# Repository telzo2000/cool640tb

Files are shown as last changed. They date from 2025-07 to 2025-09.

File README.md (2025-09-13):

# cool640tb

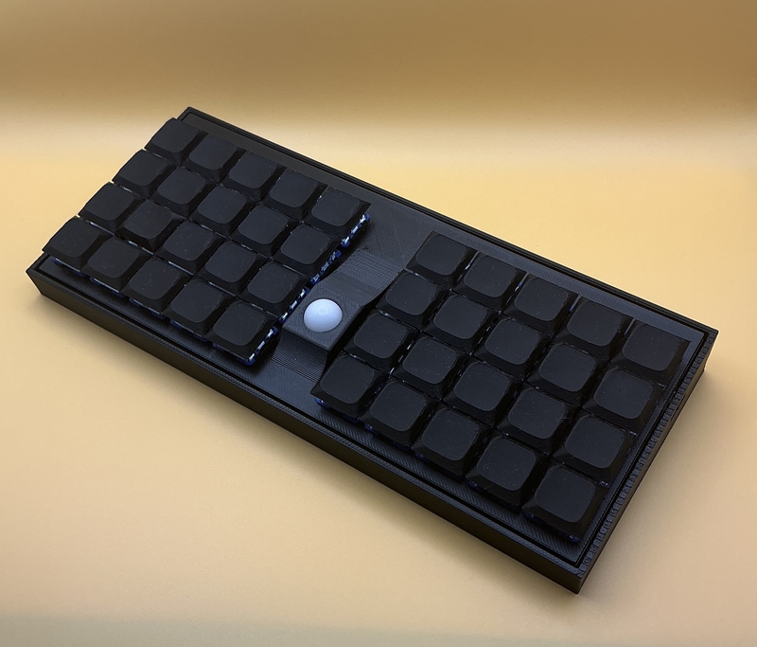
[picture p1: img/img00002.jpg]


## What is cool640tb?

cool640tb is ortholiner keyboard with trackball.

<br>
cool640tb use seeed xiao ble,run zmk_firmware.
<br>
<br>

作った理由
<br>
https://sizu.me/m_ki/posts/i3df5xan90us
<br>

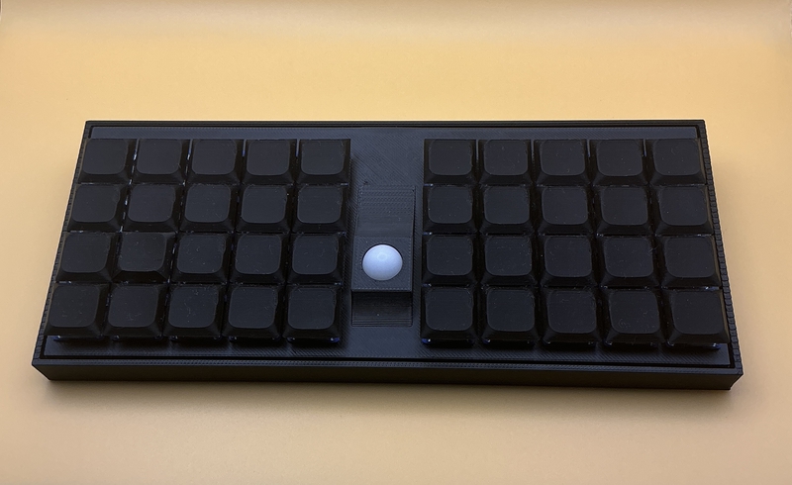
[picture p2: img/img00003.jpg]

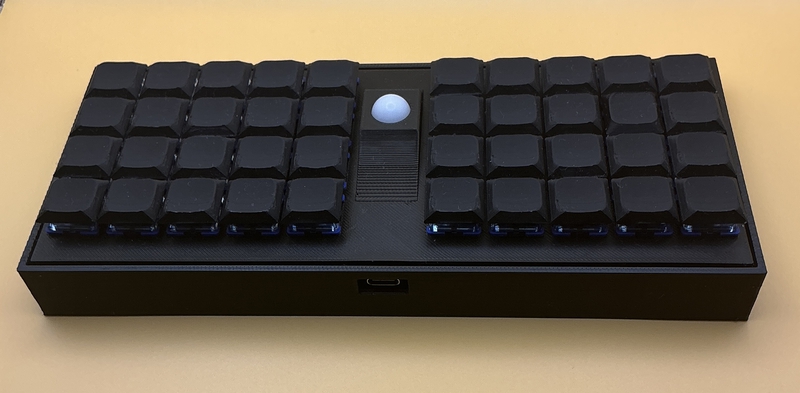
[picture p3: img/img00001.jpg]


## firmware

[zmk-config](https://github.com/telzo2000/zmk-config-cool640tb)

<br>
keymap editor

https://nickcoutsos.github.io/keymap-editor/

<br>
zmk studio

https://zmk.studio/

<br>

自作キーボードへのzmk_firmwareのインストールについて

https://sizu.me/m_ki/posts/kvixkn2mec6a

<br>
zmk_firmwareでのキーマップ編集について

https://sizu.me/m_ki/posts/m3devs7be5km

<br>

## buildguide

https://github.com/telzo2000/cool640tb/blob/main/buildguide_for_cool640tb.md

<br>
組み立てたけど、キーが反応しない時は
<br>
https://sizu.me/m_ki/posts/3vcc3izdt1w4
<br>

<br>

## BOM
<b>common parts</b>
| No. | Patrs | Quantity | remarks | Suppliers | Cost |
|--|--|--|--|--|--|
|番号|名前|数|備考|調達先|参考価格（送料込）|<br>
|1|PCB|1||[elecrow](https://www.elecrow.com)<br>[JLCPCB](https://jlcpcb.com)<br>[ALLPCB](https://www.allpcb.com)||<br>
|2|Top case|1|3D Print|||
|3|Bottom case|1|3D Print|||
|4|Switch knob|1|3D Print|||
|5|Slide switch<br>スライドスイッチ|1||[秋月電子](https://akizukidenshi.com/catalog/g/g115370/)|１個30円|
|6|AAAA Battery case<br>単４電池ケース|2||[秋月電子](https://akizukidenshi.com/catalog/g/g102670/)|１個40円|
|7|XIAO nRF52840 Plus|1|MCU Board|[seeed studio](https://www.seeedstudio.com/Seeed-Studio-XIAO-nRF52840-Plus-p-6359.html)<br>[スイッチサイエンス](https://www.switch-science.com/products/10468?srsltid=AfmBOop922ZEHWC7FqFZZKFmG-2YqUAAqYu5usYdPweG1f1-7KqjcMUV)|2139円|
|8|Diode<br>ダイオード|40|SMD|[遊舎工房](https://yushakobo.jp)<br>[Talp Keyboard](https://talpkeyboard.net)<br>[Daily Craft Keyboard](https://shop.dailycraft.jp)等|100個で220円程度から|
|9|Switch socket<br>スイッチソケット|40|choc|[遊舎工房](https://yushakobo.jp)<br>[Talp Keyboard](https://talpkeyboard.net)<br>[Daily Craft Keyboard](https://shop.dailycraft.jp)等|10個で165円程度|
|10|Screw<br>ネジ|2|スリムヘッドM2 3mm|[遊舎工房](https://shop.yushakobo.jp/products/a0800s3)|50本550円(遊舎工房)|
|11|Screw<br>ネジ|2|M2 4mm|DIY shop|10本200円程度|
|12|Spacer<br>スペーサー|2|M2 6mm|DIY shop|10本400円程度|
|13|Keyswitch<br>キースイッチ|40|chocV1及びV2対応|[遊舎工房](https://yushakobo.jp)<br>[Talp Keyboard](https://talpkeyboard.net)<br>[Daily Craft Keyboard](https://shop.dailycraft.jp)|１個100程度|
|14|Keycap<br>キーキャップ|40|16.8mm以下の狭ピッチ、ロープロが最適|3D Print||
|15|ball<br>ボール|1|12mm球|[アリエク](https://ja.aliexpress.com/item/1005004971601859.html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)|50個で500円ぐらい|
|16|PMW3610|1|Trackball senser|[アリエク](https://ja.aliexpress.com/item/1005007622547772.html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)|1000円ぐらい|
|17|リセットスイッチ（タクトスイッチ）|1||[秋月電子](https://akizukidenshi.com/catalog/g/g108073/)|１個20円|
|18|センサー基板|1|PWM3610に使用する。７ピンのピンヘッダまたはコンスルーが必要||[Data](https://github.com/telzo2000/cool942tb/tree/main/gbr/PWM3610/gbr)|

In addition, NiHM rechargeable batteries (4 AAA size), USB cable, etc. are required.
<br>
この他に、NiHM充電池（単４形2本）、USBケーブル等が必要です。
<br>
狭ピッチのキーキャップについては、次のサイトを利用して作成し、3Dプリンタで印刷しました。

[Maker World](https://makerworld.com/ja/makerlab/parametricModelMaker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)

# license

[CC BY-NC-SA](https://creativecommons.org/licenses/by-nc-sa/4.0/deed.ja)



2025.09.13追加　ケースデザインに必要となるdxf書類をアップロードしました。ライセンスの除外事項として、cool640tbをm.kiのboothから購入した方が、オリジナルケースをデザインし、有償及び無償にて配布することは可能とします。

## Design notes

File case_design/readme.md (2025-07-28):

PCB ver.1.1は、V110フォルダ内にあるケースデータを使用してください。
<br>

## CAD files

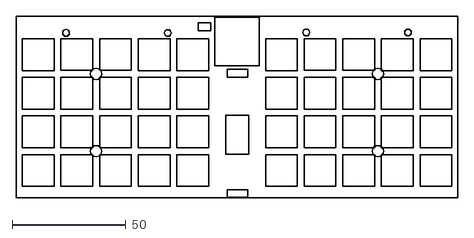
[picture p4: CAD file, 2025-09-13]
case_design/cool640tb-User_Eco2.dxf
194.1 x 79.7

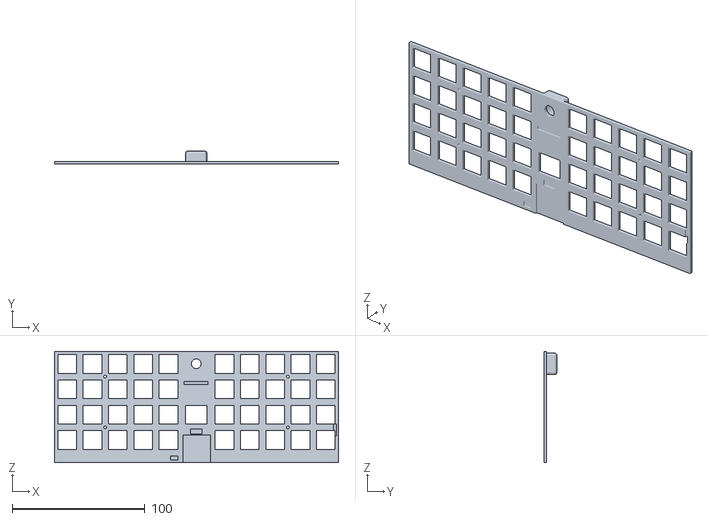
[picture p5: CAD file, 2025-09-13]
case_design/cool640tb2_v100/cool640tb2_switcplate.stl
213.5 x 9.89 x 83.8

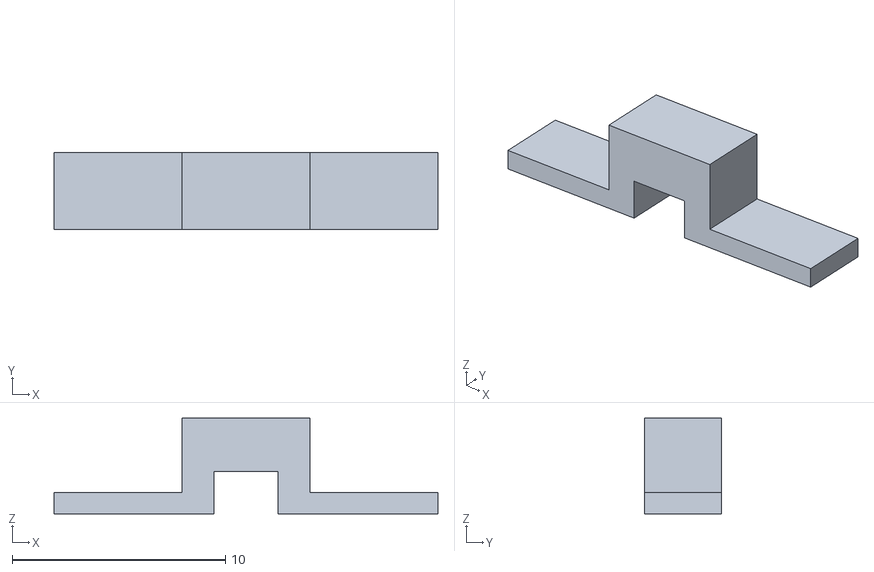
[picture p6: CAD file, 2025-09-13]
case_design/V120/cool640tb_switch_knob.stl
18.0 x 3.60 x 4.50

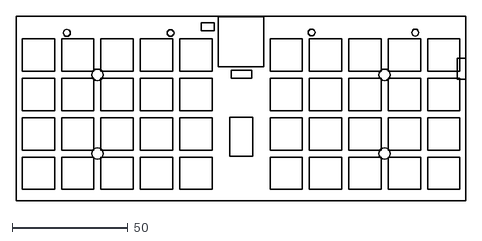
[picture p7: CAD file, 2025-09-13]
case_design/cool640tb-User_Eco1.dxf
194.1 x 79.7

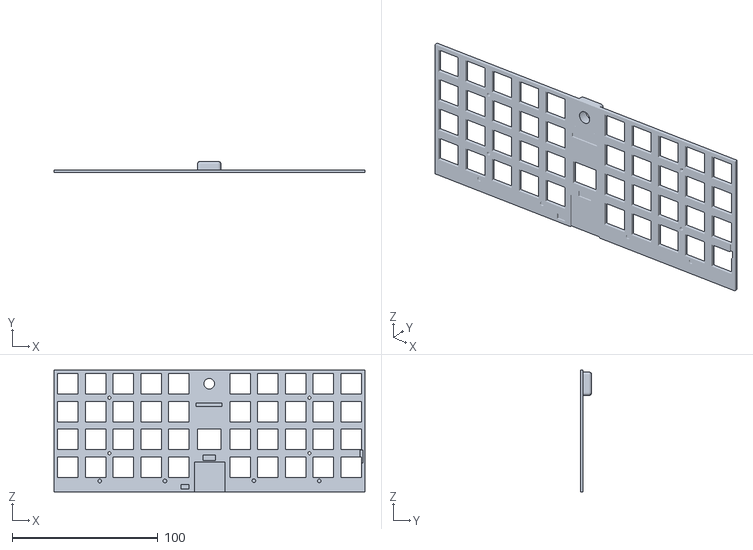
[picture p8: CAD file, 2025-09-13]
case_design/cool640tb2_v100/cool640tb2_switchplate.stl
213.5 x 7.89 x 83.8

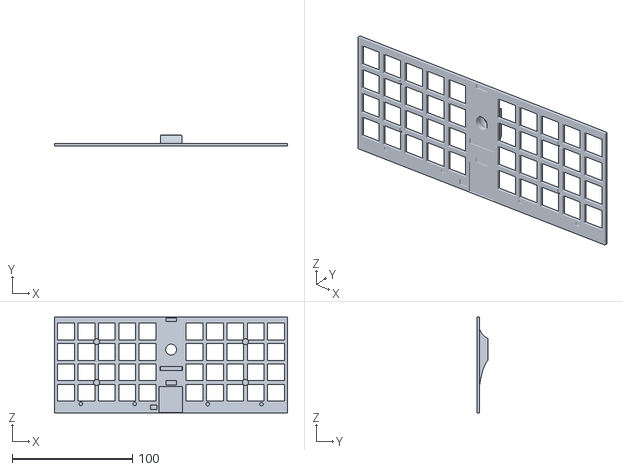
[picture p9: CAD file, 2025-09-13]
case_design/V120/cool640tb_switcplate.stl
194.1 x 9.22 x 79.7

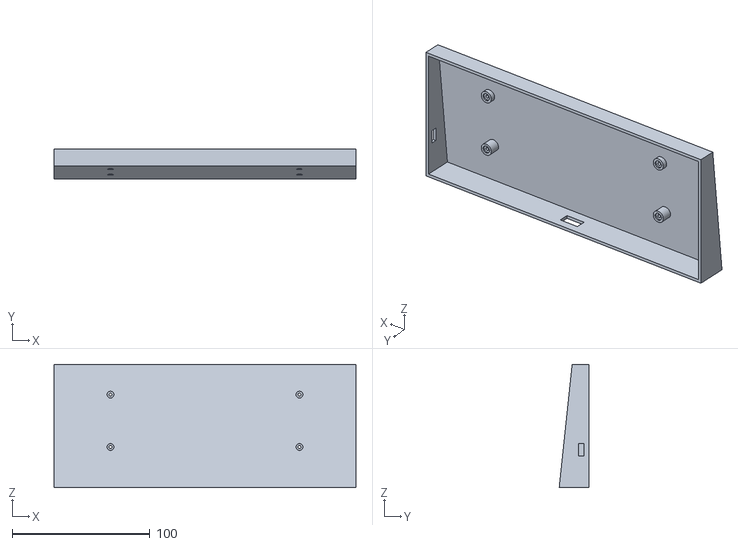
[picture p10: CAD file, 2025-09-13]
case_design/cool640tb2_v100/cool640tb2_bottomcase.stl
219.5 x 21.6 x 89.8

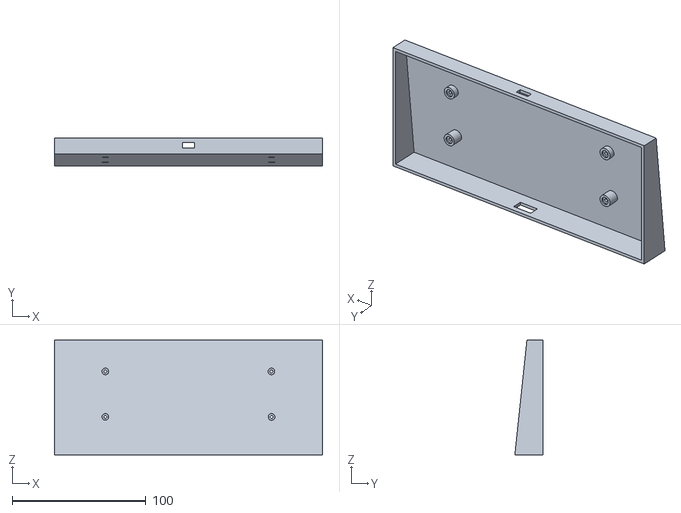
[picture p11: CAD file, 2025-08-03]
case_design/V120/cool640tb_bottomcase.stl
200.1 x 21.2 x 85.7

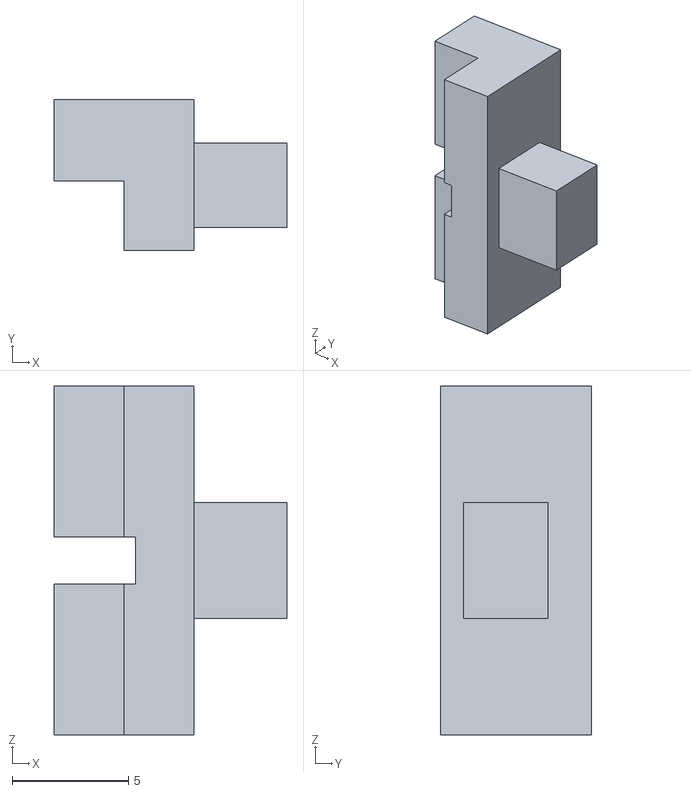
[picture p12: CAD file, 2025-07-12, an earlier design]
case_design/v110/old_design/cool640zmk_knob.stl
10.0 x 6.50 x 15.0

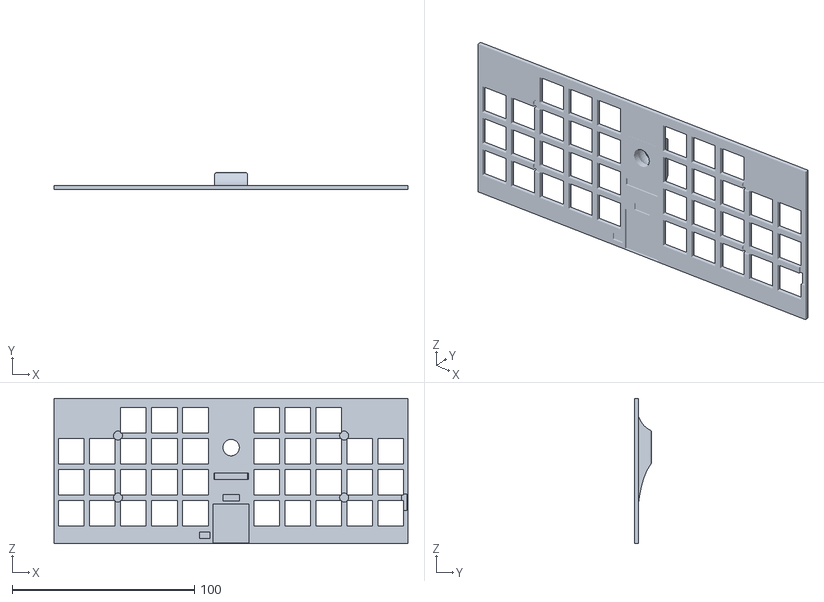
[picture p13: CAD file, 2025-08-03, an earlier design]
case_design/v110/cool640tb_switchplate_easy_36.stl
194.1 x 9.22 x 79.7

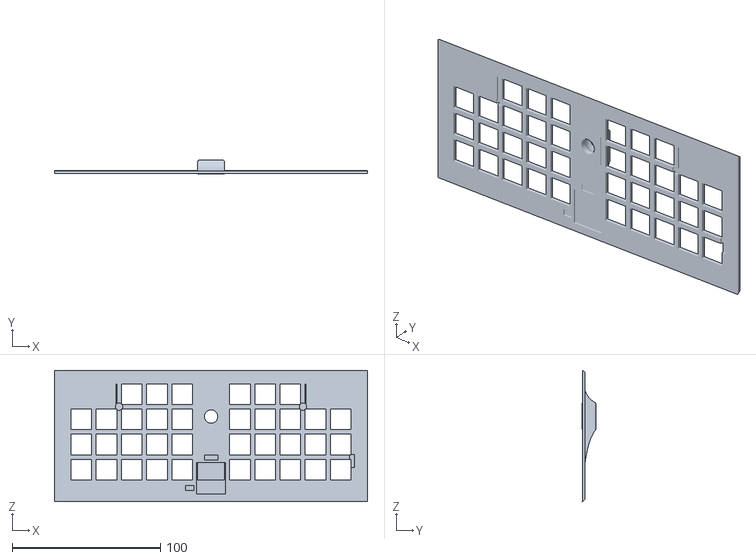
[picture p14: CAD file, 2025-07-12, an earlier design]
case_design/v110/old_design/cool640tb36_topcase.stl
211.1 x 9.22 x 88.5

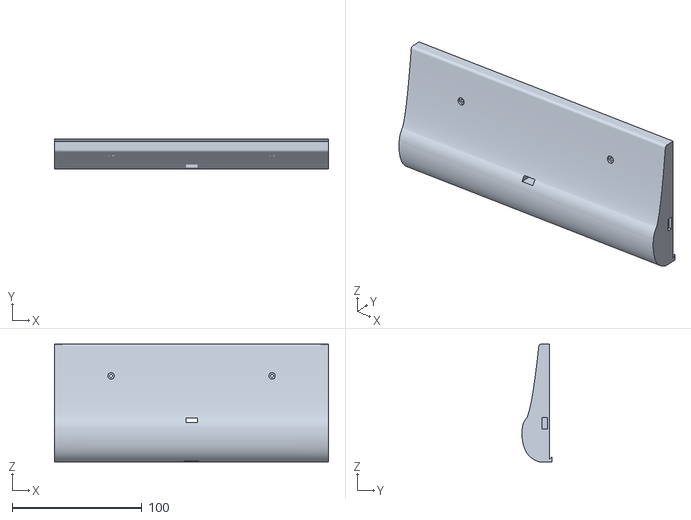
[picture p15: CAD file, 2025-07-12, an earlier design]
case_design/v110/old_design/cool640tb_bottomcase.stl
211.1 x 23.3 x 90.8

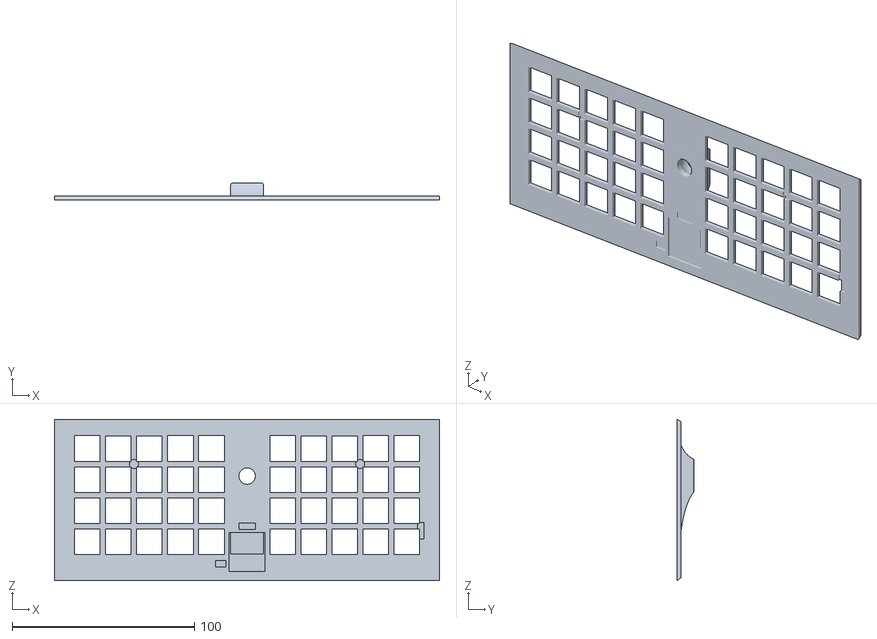
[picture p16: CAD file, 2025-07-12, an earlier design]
case_design/v110/old_design/cool640tb_topcase.stl
211.1 x 9.22 x 88.5

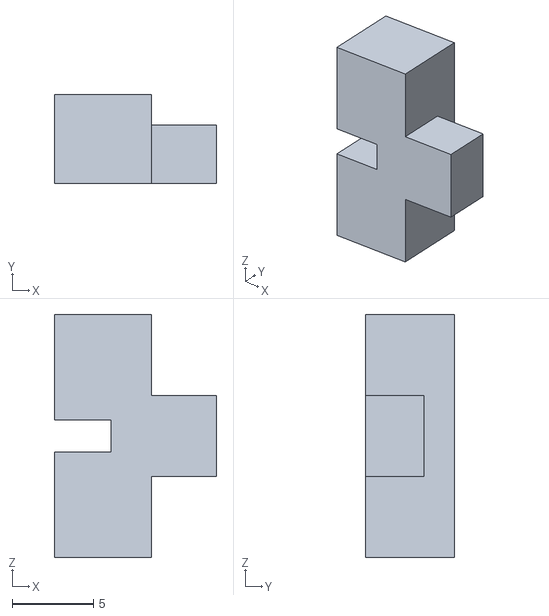
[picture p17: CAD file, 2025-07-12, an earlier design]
case_design/v110/old_design/cool640zmk_knob2.stl
10.0 x 5.50 x 15.0

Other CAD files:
case_design/v110/cool640tb_switchplate_easy.stl
case_design/v110/cool640tb_bottomcase_easy.stl
case_design/v110/old_design/cool640zmk_bottomcase.stl
case_design/v110/old_design/cool640tb_knob.stl

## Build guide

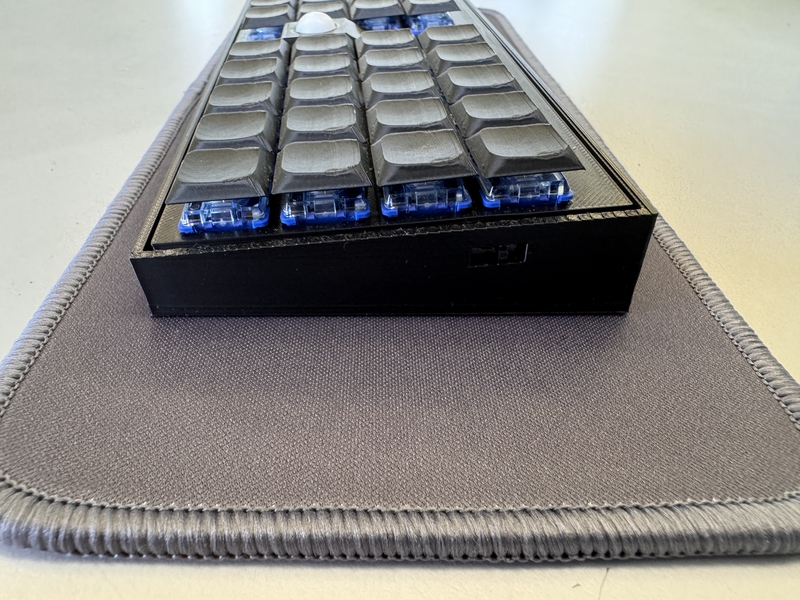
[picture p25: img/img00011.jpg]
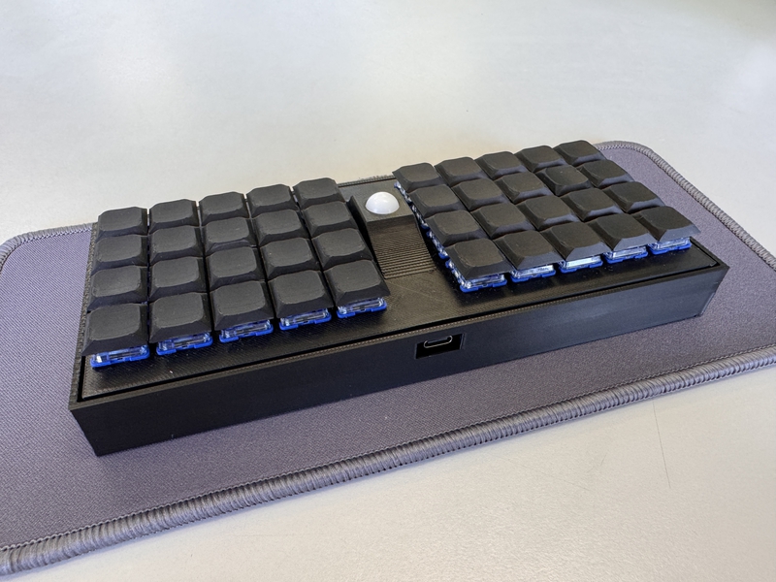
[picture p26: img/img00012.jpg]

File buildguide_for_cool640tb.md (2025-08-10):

# Buildguide for cool640tb

<br>

## 0 部品の確認
<br>
Follow the BOM on github's readme.md to make sure that all the parts are available.
<br>
githubのreadme.mdのBOMに沿って、部品が全て揃っているかを確認してください。
<br>

## 1 ダイオードのはんだ付け

If the diode is already soldered, please skip this operation.
<br>
すでにダイオードのはんだ付けされている場合は、この作業を省略してください。
<br>
<br>
This work is done on the left and right keyboard boards respectively.
<br>
この作業は左右のキーボード基板でそれぞれ行います。
<br> 
Solder the diodes to the back of PCB.
<br>
PCBの裏面にダイオードのハンダ付けをします。
<br>
As expected, it is compatible with SMD type.
<br>
ダイオードは、SMDタイプに対応しています。
<br>
Diodes have polarity, so be careful about the direction in which they are installed.
<br>
ダイオードには極性がありますので、取り付ける向きに注意してください。
<br>

[ダイオード（SMD)のはんだ付けの動画](https://youtu.be/ODk16bd4XkA)
<br>
[ダイオード（リードタイプ）のはんだ付けの動画](https://youtu.be/lbAQkKzNawM)
<br>
[ダイオード（リードタイプ）のはんだ付けの動画２](https://youtu.be/3hWZjaBROL8)

<br>

## 2  スイッチソケットのハンダ付け

cool640tb supports choc switch sockets.
<br>
cool640tbでは、chocのスイッチソケットに対応しています。
<br><br>
Solder the switch socket to the back of the keyboard board.
<br>
キーボード基板の裏面にスイッチソケットのハンダ付けをします。
<br>

[Switch socketハンダ付け動画](https://youtu.be/ZnbgaueMR4w?si=_JLjD--3HJJ5Pu7Q)

<br>

## 3 Seeed xiao ble Plus(xiao nRF 52840 Plus)のハンダ付け

<b>Note</b>
<br>
次の動画を参考にしてハンダ付けをしてください。
<br>
[xiao ble Plusのハンダ付け動画](https://youtu.be/T4O7NxNUMdo)

## 4  電池ボックス取り付け

Insert the battery box from the bottom of the board and temporarily fix it in place with masking tape. Then, cut off the leads sticking out from the top of the board with pliers or something similar, and solder them.
<br>
電池ボックスを基板の下面から、差し込み、マスキングテープで仮固定します。そして、基板の上面から飛び出したリードをニッパーなどで切り取り、ハンダ付けをしてください。
<br>

## 5 スライドスイッチのハンダ付け

Insert the switch from the underside of the PCB with the tab facing outwards.
<br>
スイッチのつまみが外側に向くようにして、PCBの下面から差し込みます。
<br>
Temporarily fix it in place with masking tape or something similar, then cut off the part sticking out on the top surface of the PCB with pliers, and then solder it.
<br>
マスキングテープなどで仮固定をしてから、PCBの上面に出た部分をニッパーで切り取ってから、はんだ付けします。
<br>

[スライドスイッチのはんだ付けの作業動画](https://youtu.be/5nkRklibay4)

<br>

## 6 リセットスイッチのハンダ付け

The switch button faces down and is inserted into the underside of the PCB.
<br>
スイッチのボタンが下に向くようにして、 PCBの下面から差し込みます。
<br>
Temporarily fix it in place with masking tape or something similar, then cut off the part sticking out on the top surface of the PCB with pliers, and then solder it.
<br>
マスキングテープなどで仮固定をしてから、PCBの上面に出た部分をニッパーで切り取ってから、はんだ付けします。

[リセットスイッチハンダ付け動画](https://youtu.be/Pl24Exfh8b8)

## 7 トラックボール基板の作成

Caution PMW3610 is prone to sensor damage when exposed to high temperature heat. Please complete the soldering of each pin in a short time.
<br>
注意　PMW3610は高温の熱にさらされるとセンサーの破損が発生しやすいです。それぞれのピンのはんだ付けは短時間で済ませてください。
<br>
As for my example, soldering is processed in 2-3 seconds per pin.
<br>
私の例ですが、はんだ付けを１つのピンにつき、2〜3秒で処理します。
<br>
<br>
Note: The silk of "Front side" and "Back side" on the board is written for the ball.
<br>
注意　基板に「Front side」や「Back side」のシルクは、ボールに対しての表記です。
<br>
<br>
The trackball board has components installed from the beginning. The implemented side is the back side.
<br>
トラックボール基板は最初から部品が実装されています。実装されている面を裏面とします。
<br>
<br>
Remove the PWM3610 acrylic parts.
<br>
PWM3610アクリル部品を取り外します。
<br>
<br>
Check the pin of the PMW3610 and insert it from the surface of the trackball board. Temporarily fix it with masking tape.
<br>
PMW3610のピンを確認して、トラックボール基板の表面から差し込みます。マスキングテープで仮固定します。

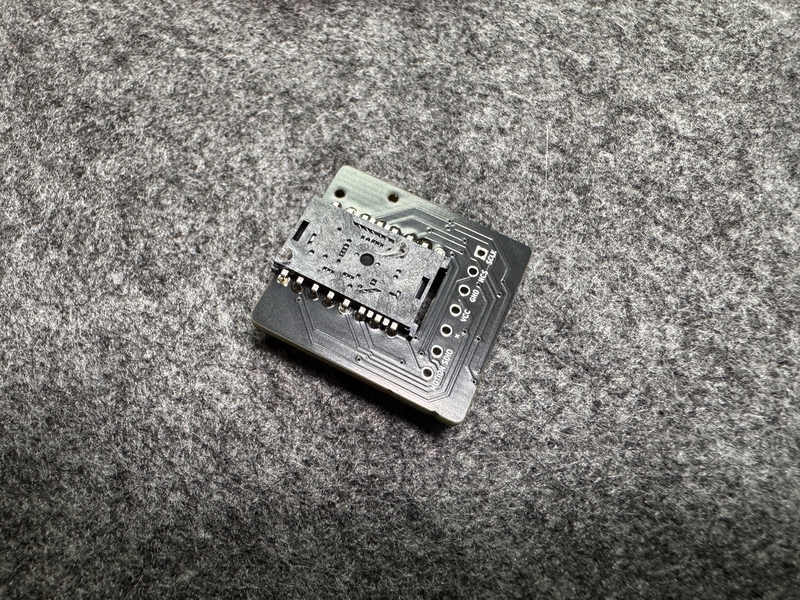
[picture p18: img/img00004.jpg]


<br>
<br>
The back of the trackball board is facing up and the part that came out of the pin hole is soldered.
<br>
トラックボール基板の裏面を上向きにして、ピン穴からでた部分をはんだ付けします。
<br>
<br>
The lens part of the PMW3610 is covered with tape, so remove it.
<br>
PMW3610のレンズ部分がテープで覆われているので、それを外します。
<br>
<br>
From the back of the trackball board, cover the acrylic part on the PMW3610, and melt the acrylic on the back with a soldering ick to prevent it from coming off.
<br>
トラックボール基板の裏面の方から、アクリル部品をPMW3610に被せて、その裏側に出たアクリルをハンダごてで溶かして外れないようにします。

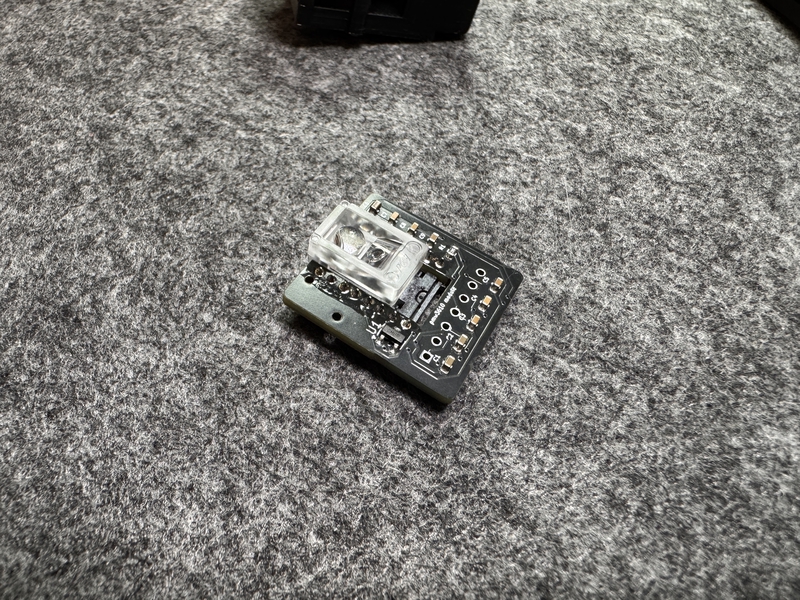
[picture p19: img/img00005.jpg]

<br>
<br>

## 8 センサー基板のはんだ付け

The sensor board created in step 7 is fixed to the circuit board by soldering it with the pin head in between.
<br>
7で作成したセンサー基板を基板にピンヘッドを間に挟んではんだ付けして固定します。
<br>

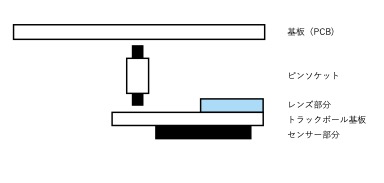
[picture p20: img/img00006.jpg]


Please refer to the diagram above when soldering. When doing so, use pliers or similar to cut off any protruding pin heads.
<br>
上の図を参考にして、はんだ付けをしてください。その際、はみ出たピンヘッドはニッパーなどで切り取ってください。
<br>

Note<br>
トラックボールセンサー基板のはんだ付けの成否を知らずに、基板にそれらをピンヘッドではんだ付けすることに不安のある場合は、７ピンの2.5mmコンスルーを使って、仮固定をすることを勧めます。仮固定で、動作に問題ないことを確認してから、コンスルーのはんだ付けをします（はんだ付けしないと、振動で外れることがあります）。
<br>
コンスルーの７ピンは通常では販売されていないので、12ピンをカッターなどで切断して用意してください。
<br>
<br>

## 9 スペーサーの装着

Insert the M2 3mm screw from the top of the board and secure it with the M2 6mm spacer from the bottom of the board.
<br>
基板の上面から、M2 3mmネジを挿入して、基板の下面からM2 6mmスペーサーで固定してください。
<br>
This is done in four places.
<br>
これは４箇所行います。
<br>

## 10　キースイッチの装着

Insert the key switch in the following order: top case, then PCB.
<br>
トップケース、PCBの順になるように、キースイッチを差し込んでください。
<br>
When inserting the key switch, make sure the pins are straight.
<br>
キースイッチを差し込む時、キースイッチのピンが真っ直ぐになっているか、確認してください。
<br>

## 11 トラックボールの装着

Place the 12mm POM ball in the designated location on the top case.
<br>
12mmPOM球をトップケースの所定の位置に装着してください。
<br>

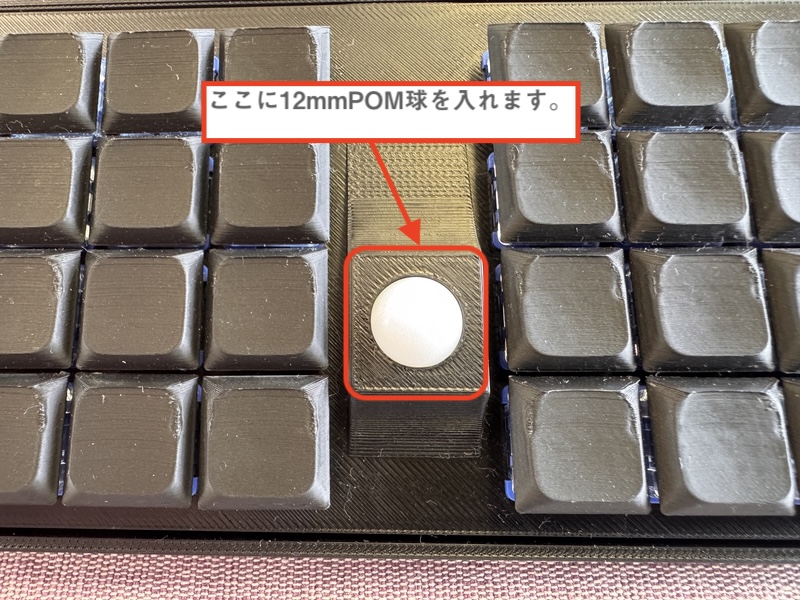
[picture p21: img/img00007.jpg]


## 12 動作確認について

ファームウェアの導入について、こちらの記事を参考にしてください。
<br>
[自作キーボードへのzmk_firmwareのインストールについて](https://sizu.me/m_ki/posts/kvixkn2mec6a)

ファームウェアは<b>[ここ](https://github.com/telzo2000/cool640tb/tree/main/firmware)</b>にあります。

<br>

Keymapの編集について、こちらの記事を参考にしてください。

[zmk_firmwareでのキーマップ編集について](https://sizu.me/m_ki/posts/m3devs7be5km)

<br>

## 9 ボトムケースの装着

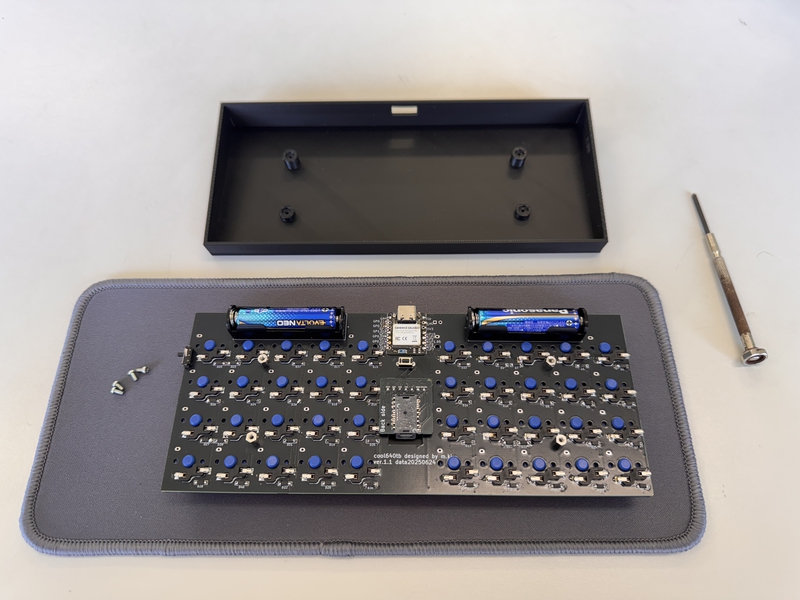
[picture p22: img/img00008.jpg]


Place the board so that the bottom side faces up. Place the bottom case on top of it. When doing so, be sure to turn on the power switch first.
<br>
基板の下面が上に向くように置きます。そこに被せるようにボトムケースを重ねます。その際、電源スイッチを先に入れるようにしてください。
<br>
<br>

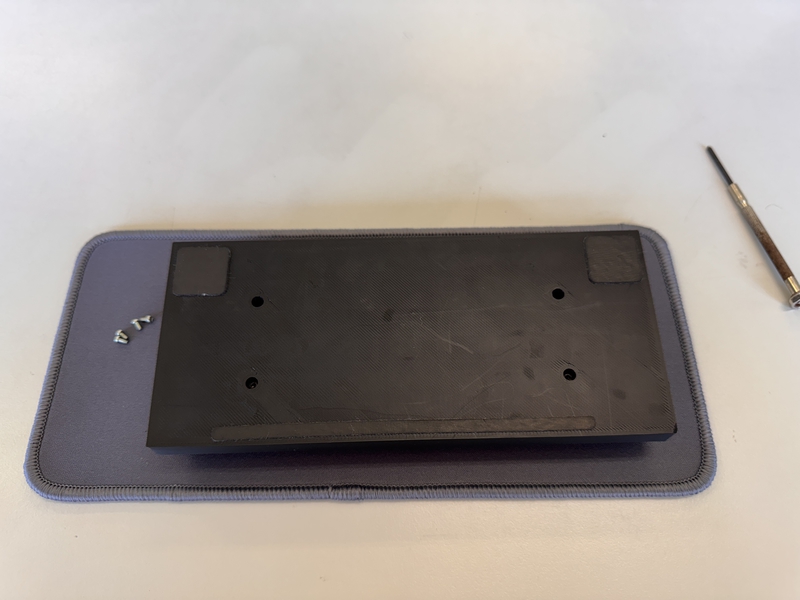
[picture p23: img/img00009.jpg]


Secure the bottom case in place by inserting M2 6mm screws into the four holes in the bottom case.
<br>
ボトムケースにある４箇所の穴に、M2 6mmネジを挿入して固定します。
<br>

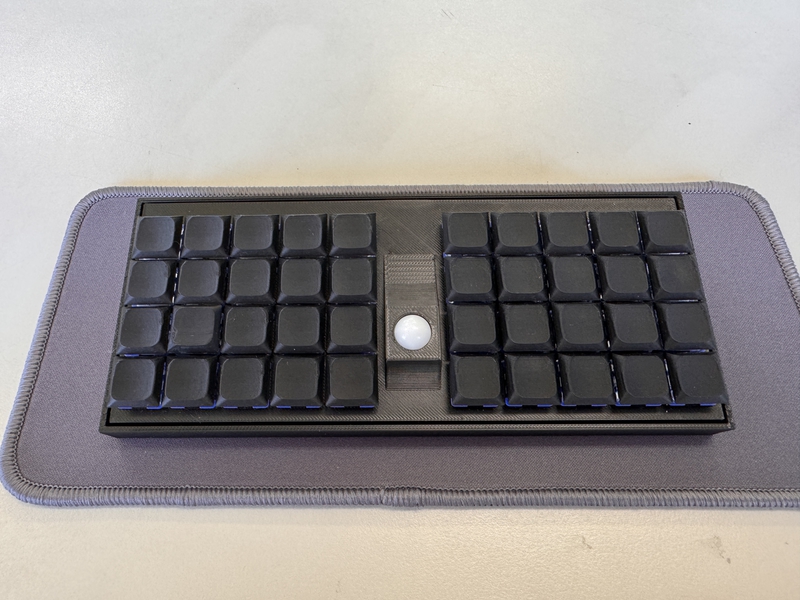
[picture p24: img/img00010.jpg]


##  10　キーキャップの装着

Please attach your favorite keycap.
<br>
お好きなキーキャップを装着してください。
<br>
<br>
This keyboard has a narrow spacing of 17mm between the keys, so you can use keycaps with four sides that are less than 17mm long.
<br>
このキーボードはキー同士の間隔が17mmと狭くなっています。そのため、キーキャップの四方の長さは17mm未満のものが使用できます。
<br>
<br>
If you are having trouble finding a place to obtain one, you can create one on [this site](https://makerworld.com/ja/models/1378891-keycap_generator#profileId-1426845).
<br>
入手先に困ったときは、[ここのサイト](https://makerworld.com/ja/models/1378891-keycap_generator#profileId-1426845)で作成することができます。
<br>

## 11 完成

After attaching non-slip rubber to the bottom of the bottom case, it's done.
<br>
Please enjoy a life with a better keyboard.
<br>
ボトムケースの底面に、滑り止めゴムを取り付けたら、完成です。
<br>
よりよいキーボードのある生活を楽しんでください。
<br>
